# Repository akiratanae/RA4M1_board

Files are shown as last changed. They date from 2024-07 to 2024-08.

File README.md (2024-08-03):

# 多機能マイコンボード
## 概要
- 手ごろな価格で入手でき、高性能で多機能なルネサス社マイコンRA4M1(R7FA4M1AB3CFM)
- USBホストまたはUSBファンクション機能をオンボードで使用可能
- RS485をオンボードで使用可能
- CANをオンボードで使用可能
- マイコン内蔵の豊富なアナログ機能をオンボードで使用可能
- 多数のマイコン端子にコネクタを通して外部からアクセス可能

# 使用法
## motorolaヘキサファイルの書込み
接続図
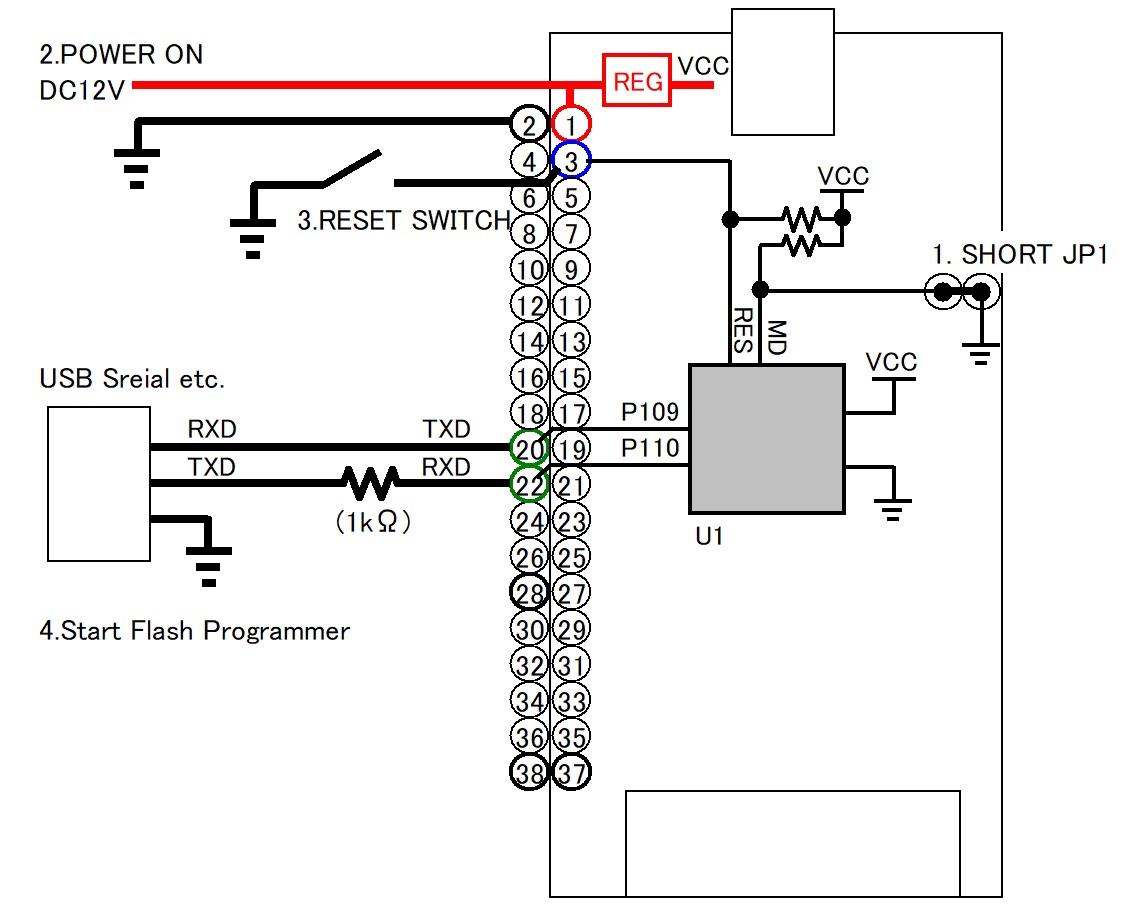
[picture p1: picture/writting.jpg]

手順  
1. JP1をショート(MD端子=LOW)
2. 電源ON
3. RES端子をLOWからHIに(図では外部リセットボタン)
4. Renesas Flash Programmerをスタート

## 使用例
外部からDC12V供給、USBホスト
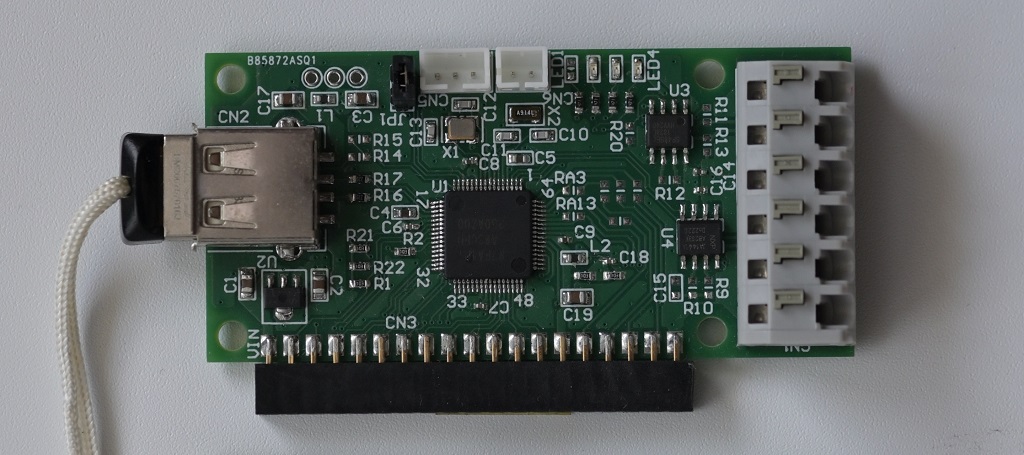
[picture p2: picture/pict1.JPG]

USBバスパワー
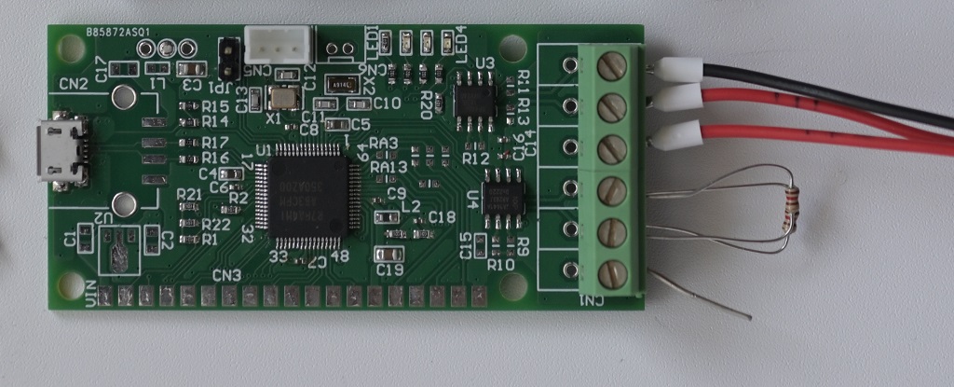
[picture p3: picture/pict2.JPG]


## versatile functional control board using renesas RA4M1 microcontroller.
- High performance and versatile but low cost microcontroller(R7FA4M1AB3CFM)
- on board USB Host or Function
- on board RS485
- on board CAN
- on chip analog functions are accessed by on board configuration
- Many pins accessible for use from outside.

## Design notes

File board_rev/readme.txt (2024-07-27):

CNTRL_SA.GTL  L1 pattern
CNTRL_SA.GBL  L2 pattern
CNTRL_SA.GTS  L1 solder resist
CNTRL_SA.GBS  L2 solder resist
CNTRL_SA.GTO  L1 silk
CNTRL_SA.GM1  mechanical outline
CNTRL_SA.TXT  drill

layer 2
size 35x74mm

revision : delete one led and add one user jumper.

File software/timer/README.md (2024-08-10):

# Simple Interrupt Software
## 概要
RA4M1のタイマ(AGT)を使用したLED点滅ソフトウェア
## e2studioでの手順
1. 新規Renesas C/C++ projectでプロジェクト作成(device=R7FA4M1AB3CFM)
2. ConfigurationのClockでクロック確認(XTAL=12MHz, ICLK=48MHzなど)
3. ConfigurationのPinでLED端子(P303,P304,P113)を出力に設定
4. ConfigurationのInterruptsでAGT0 INTイベントにISRを追加
5. Generate Project Contentボタンでコード生成
6. ra_gen/main.cをビルド対象から外す
7. srcにmain.cを追加、編集。タイマ割込みハンドラ名は4で指定したISR名
8. プロジェクトのビルド
## 備考
- IRQ(16番目から)のベクタテーブルは、ConfigurationでISR登録するとra_gen\vector_data.cに順番に作成される
- RA4M1には僅か32しか登録できる割込みベクタが無いので注意

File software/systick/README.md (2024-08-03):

# First Software
## 概要
CortexM4のSysTickタイマを使用したLED点滅ソフトウェア
## e2studioでの手順
1. 新規Renesas C/C++ projectでプロジェクト作成(device=R7FA4M1AB3CFM)
2. ConfigurationのClockでクロック確認(XTAL=12MHz, ICLK=48MHzなど)
3. ConfigurationのPinでLED端子(P303,P304,P113)を出力に設定
4. Generate Project Contentボタンでコード生成
5. ra_gen/main.cをビルド対象から外す
6. srcにmain.cを追加、編集
7. プロジェクトのビルド
## 備考
- 0番地からSysTick(15番目)までのベクタテーブルは、startup.cで設置されている

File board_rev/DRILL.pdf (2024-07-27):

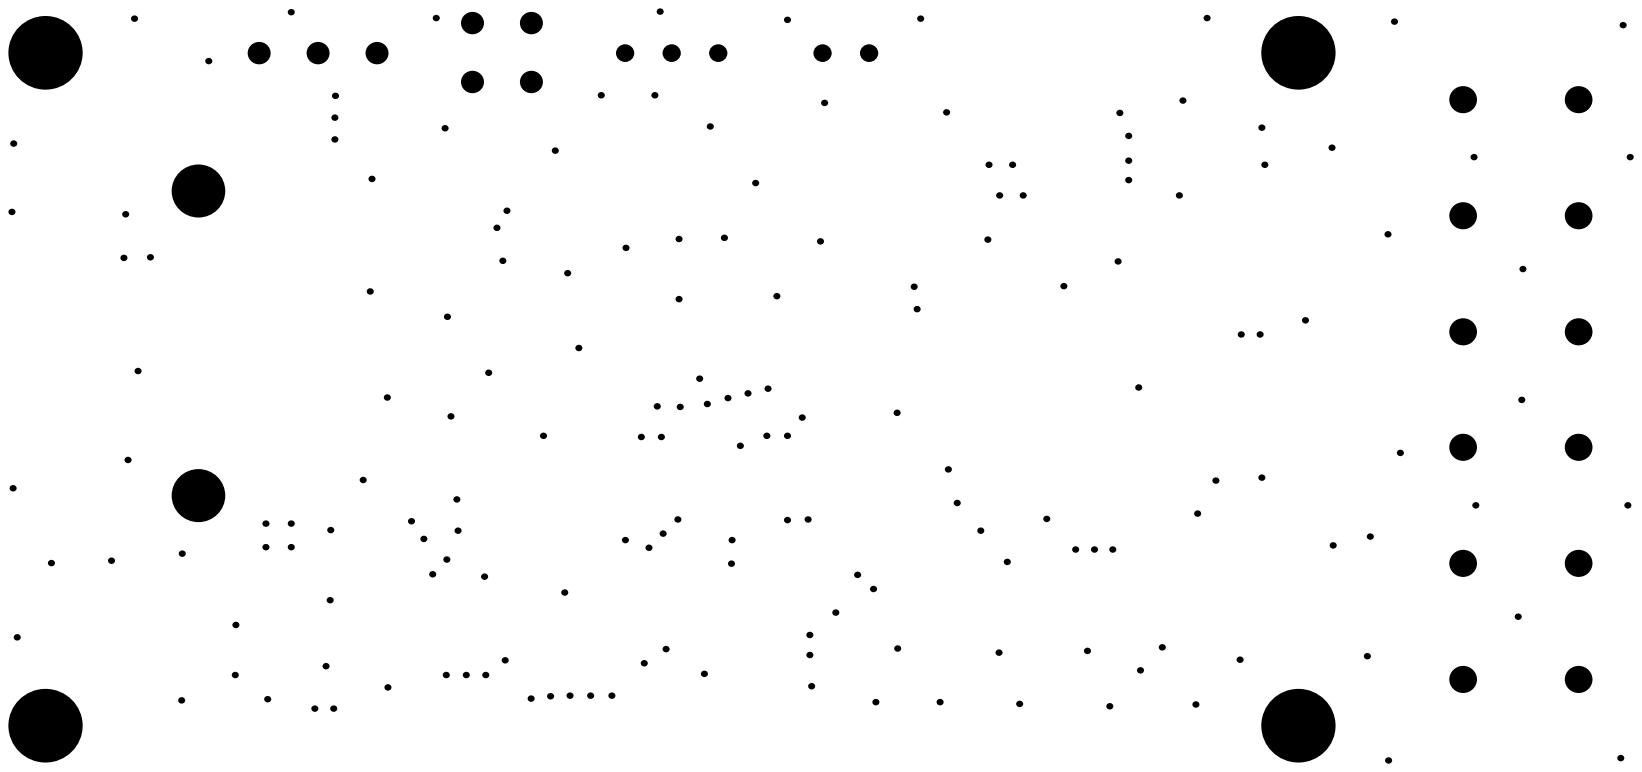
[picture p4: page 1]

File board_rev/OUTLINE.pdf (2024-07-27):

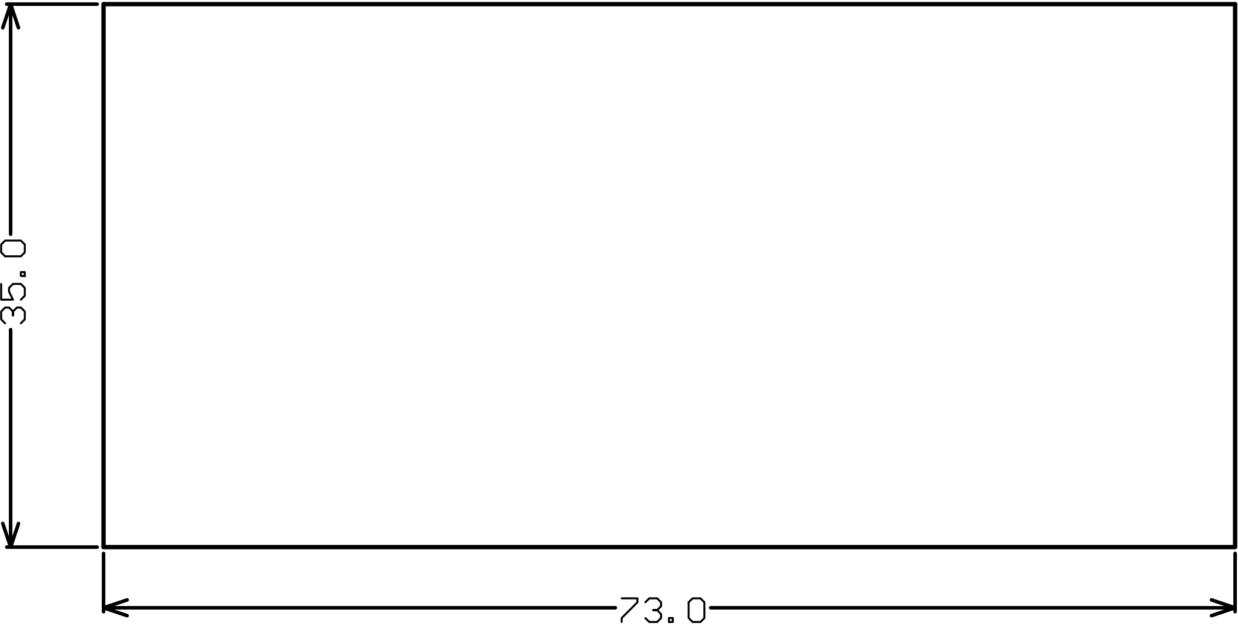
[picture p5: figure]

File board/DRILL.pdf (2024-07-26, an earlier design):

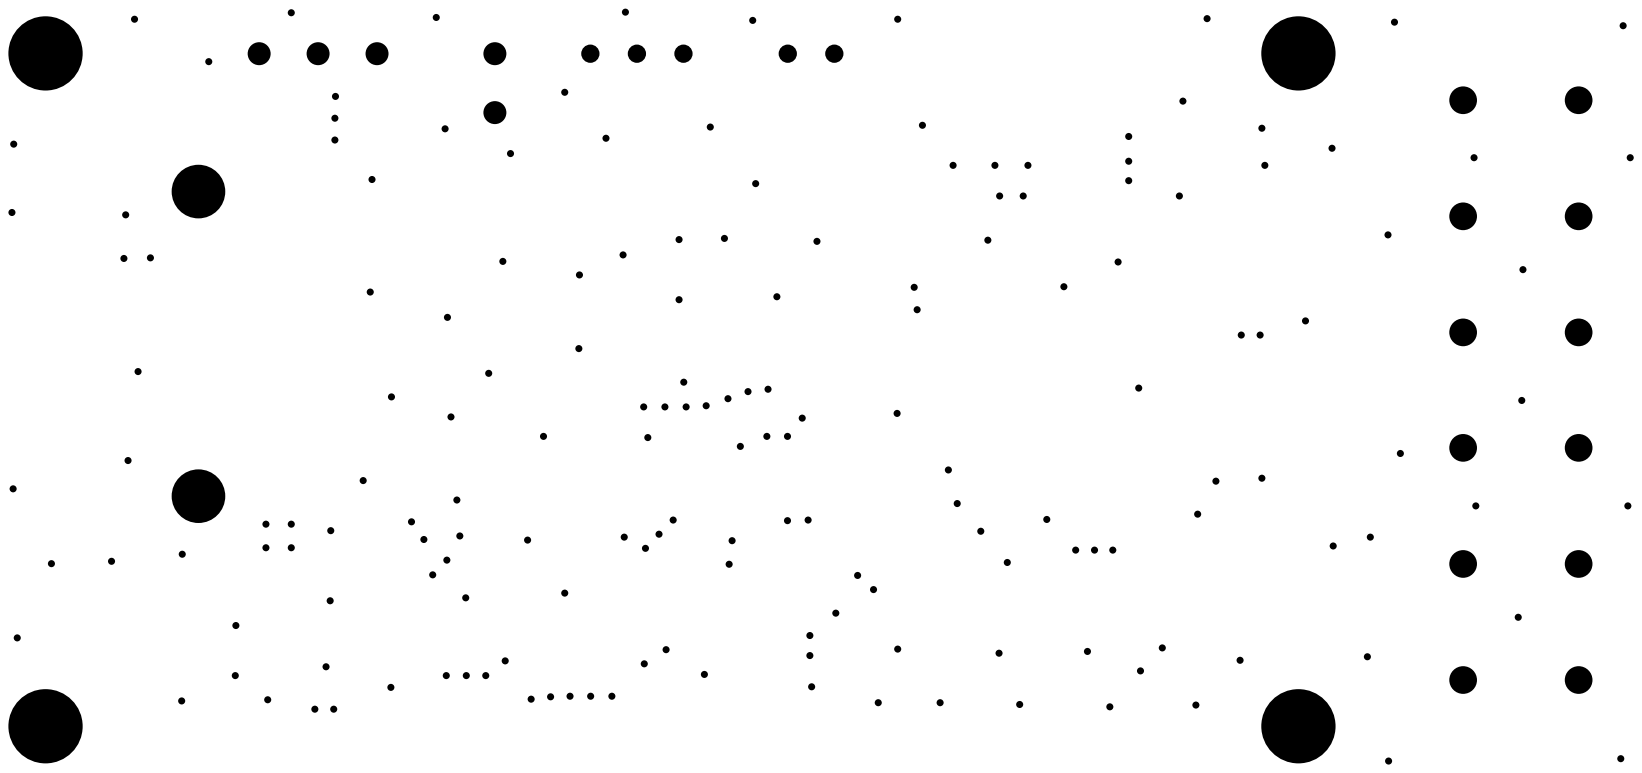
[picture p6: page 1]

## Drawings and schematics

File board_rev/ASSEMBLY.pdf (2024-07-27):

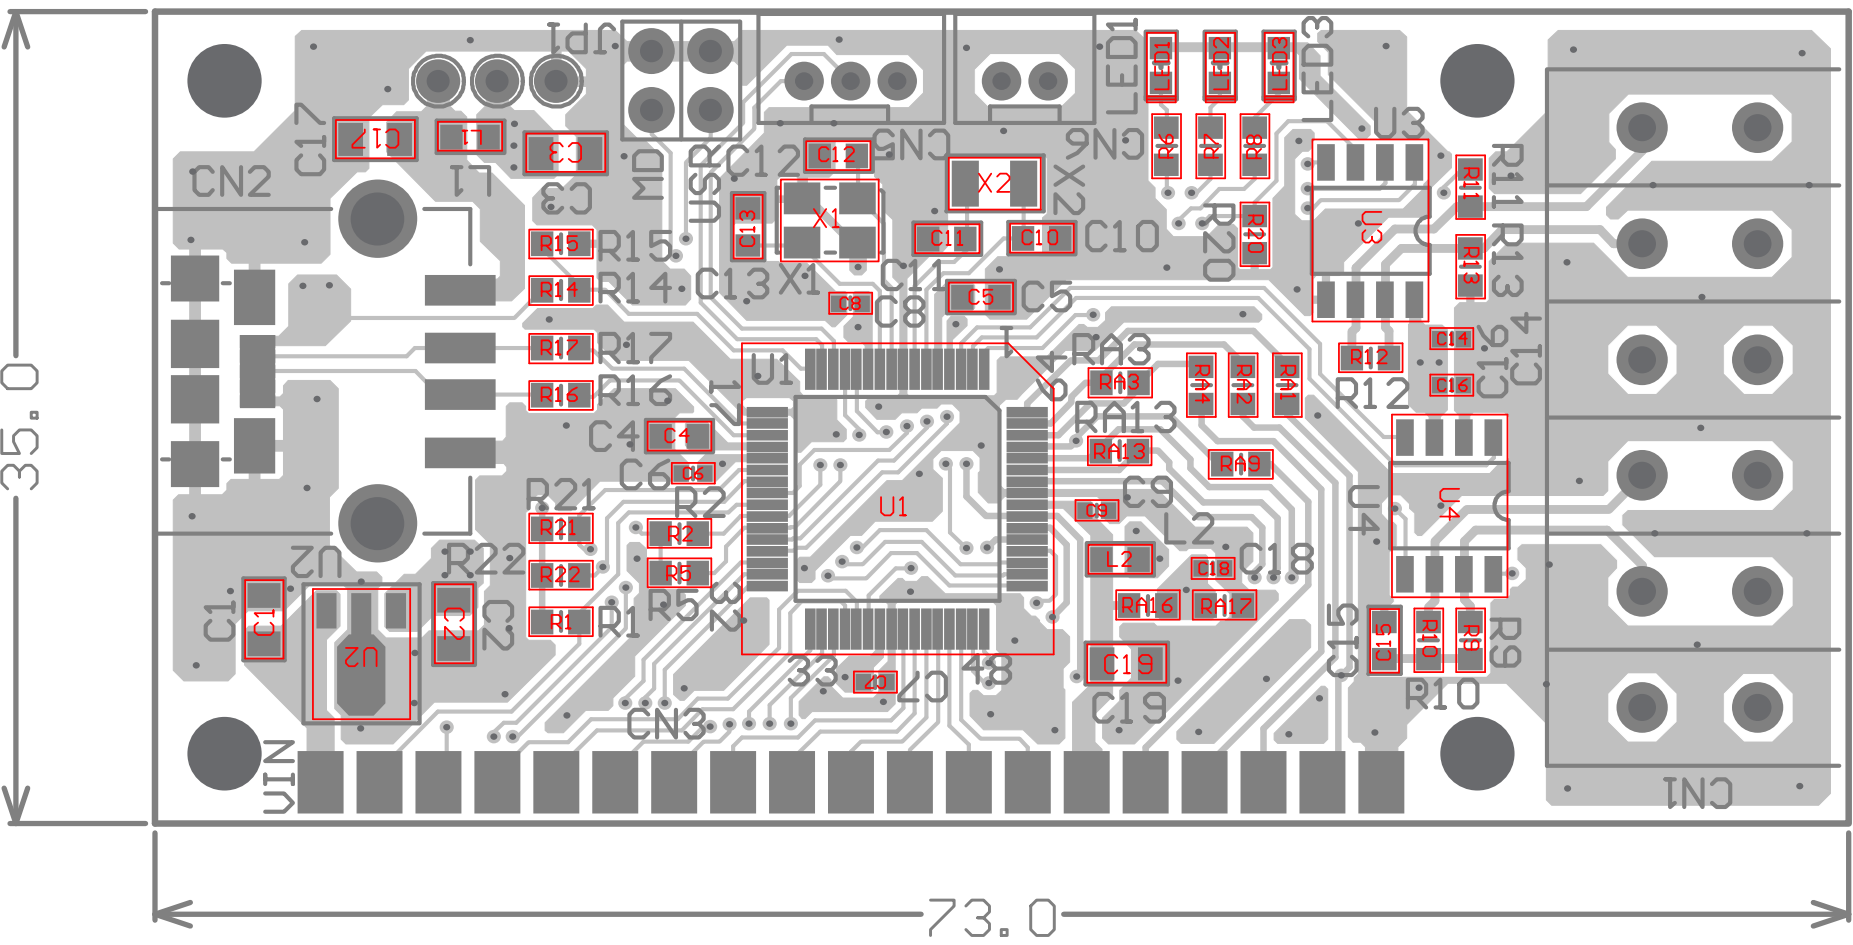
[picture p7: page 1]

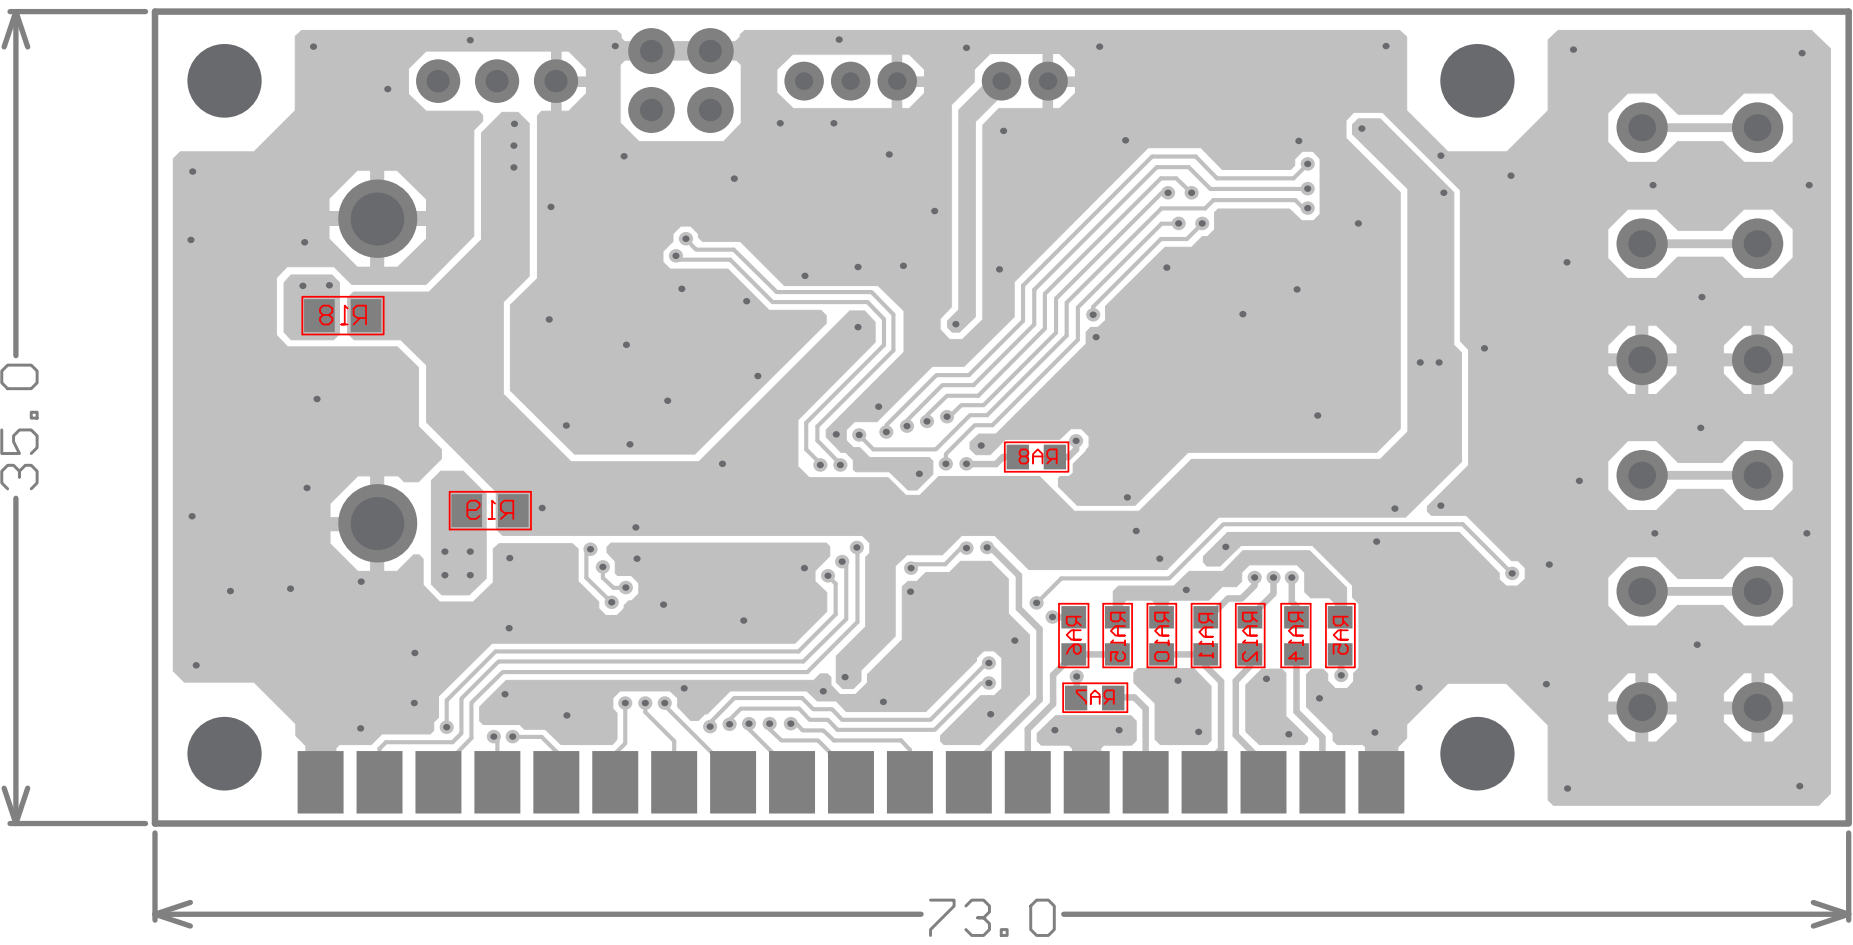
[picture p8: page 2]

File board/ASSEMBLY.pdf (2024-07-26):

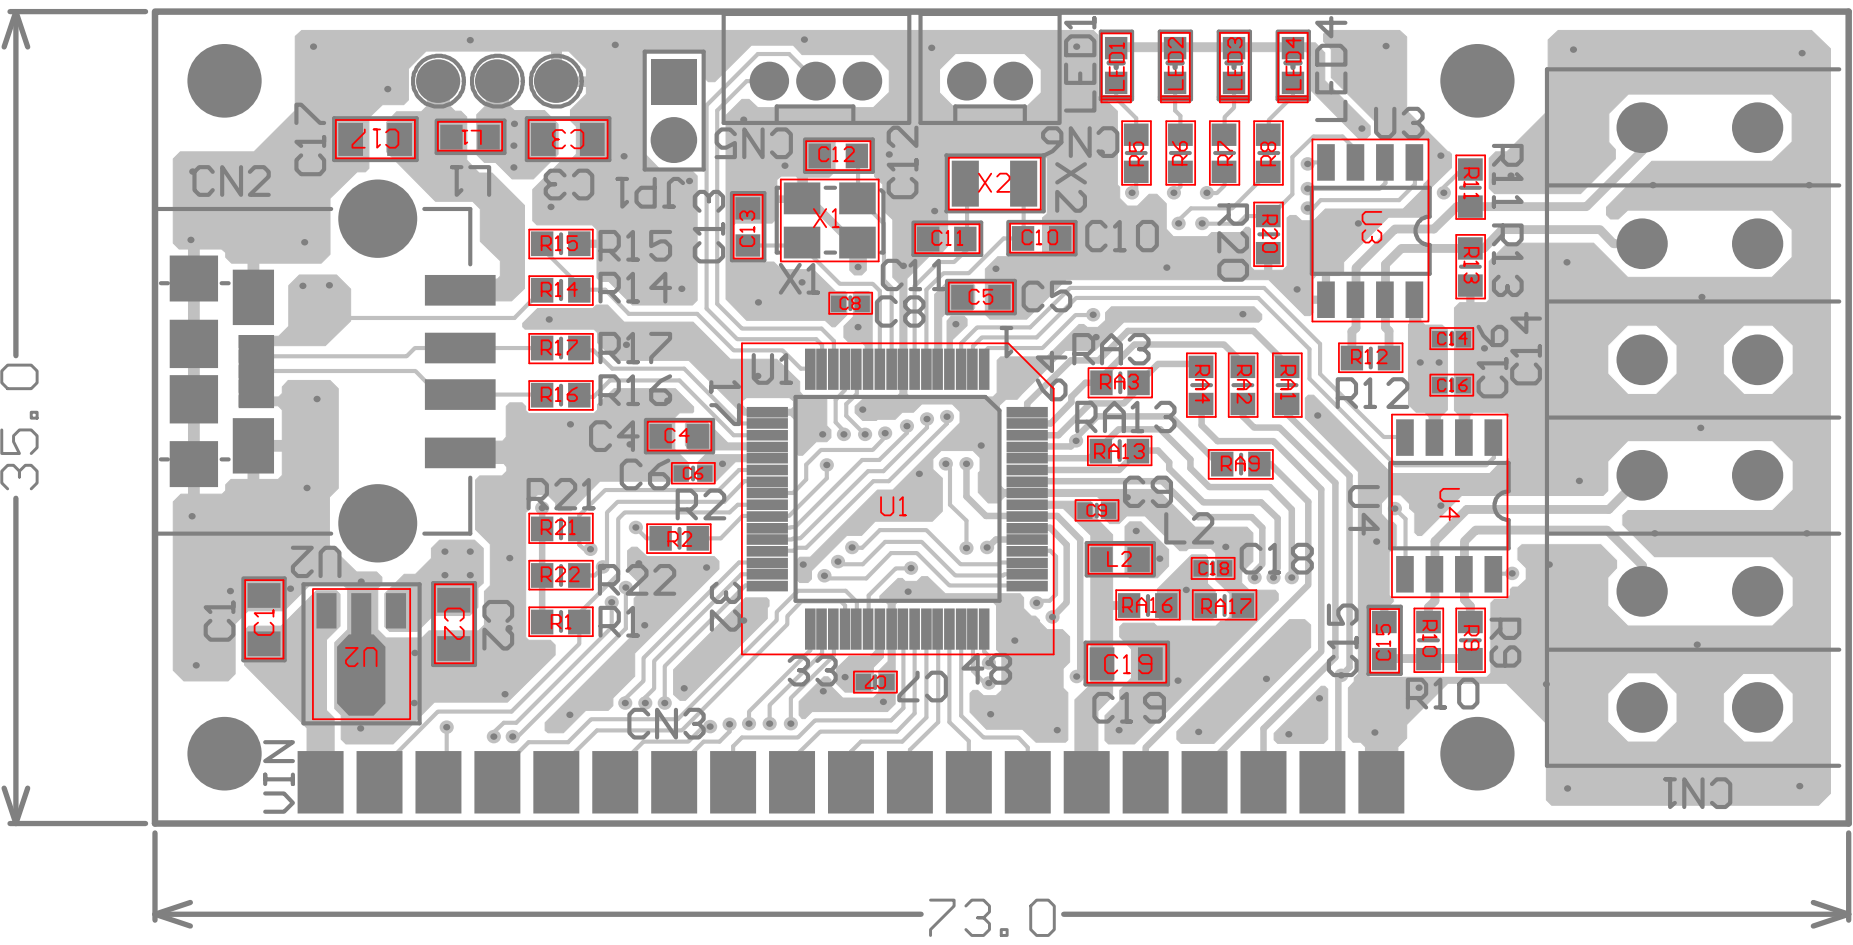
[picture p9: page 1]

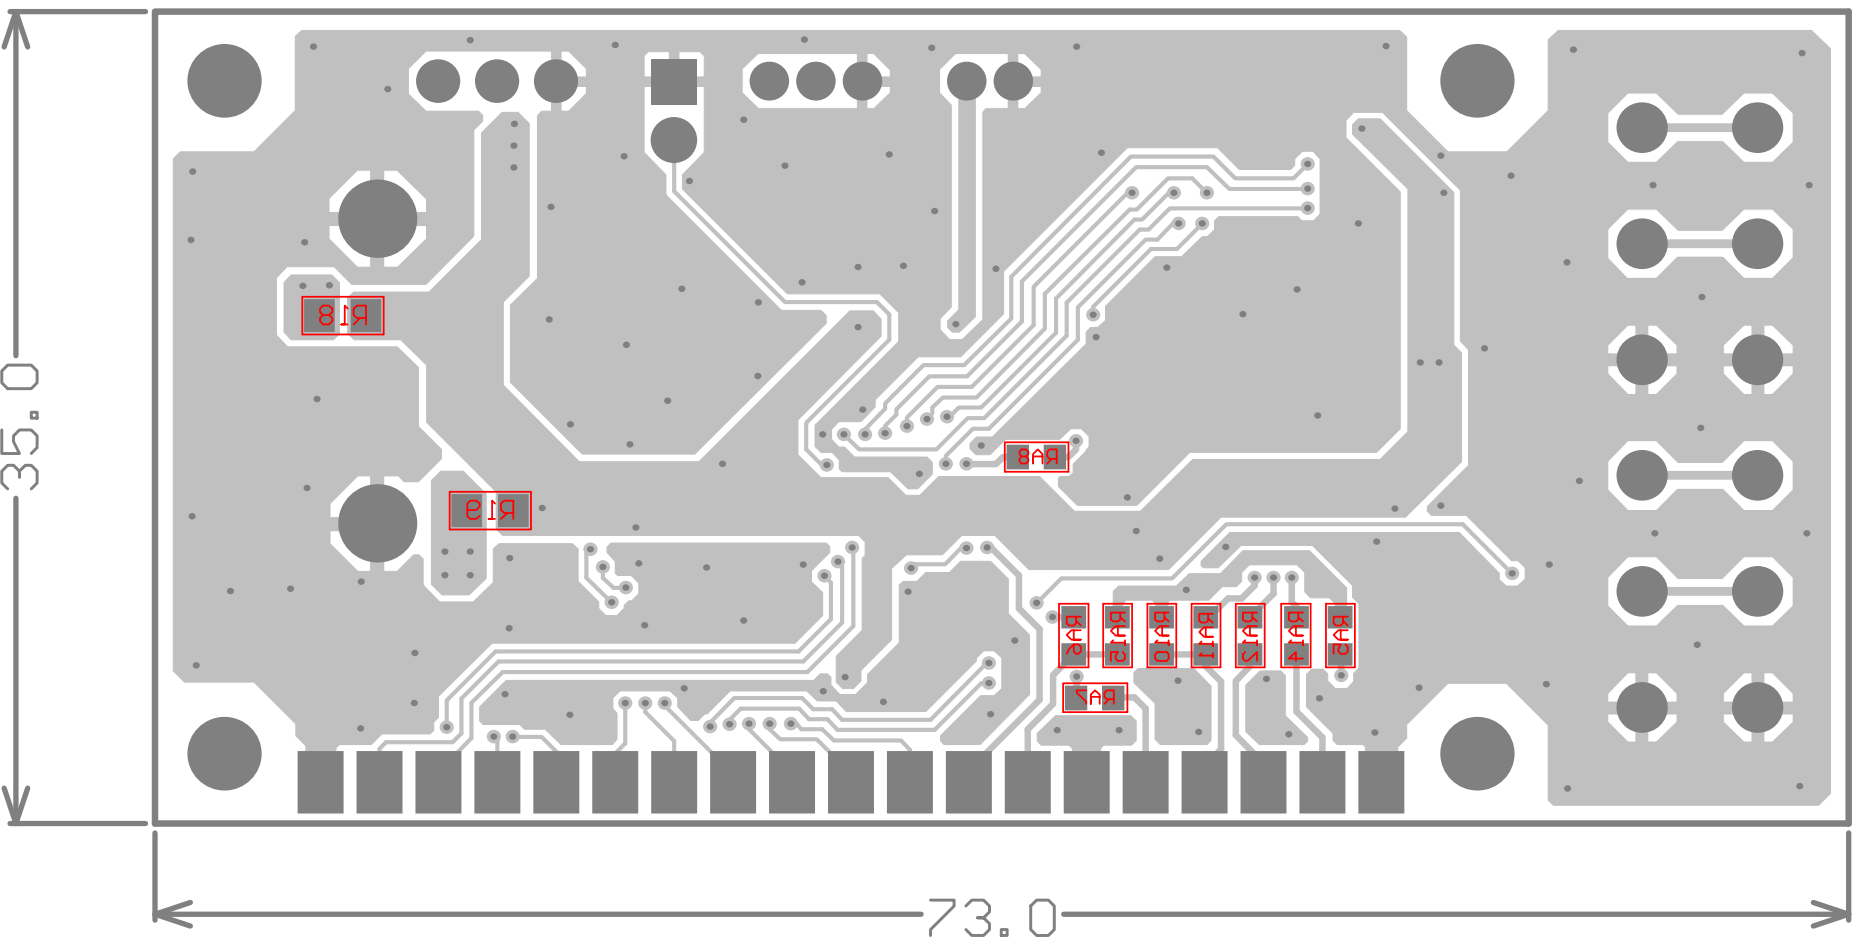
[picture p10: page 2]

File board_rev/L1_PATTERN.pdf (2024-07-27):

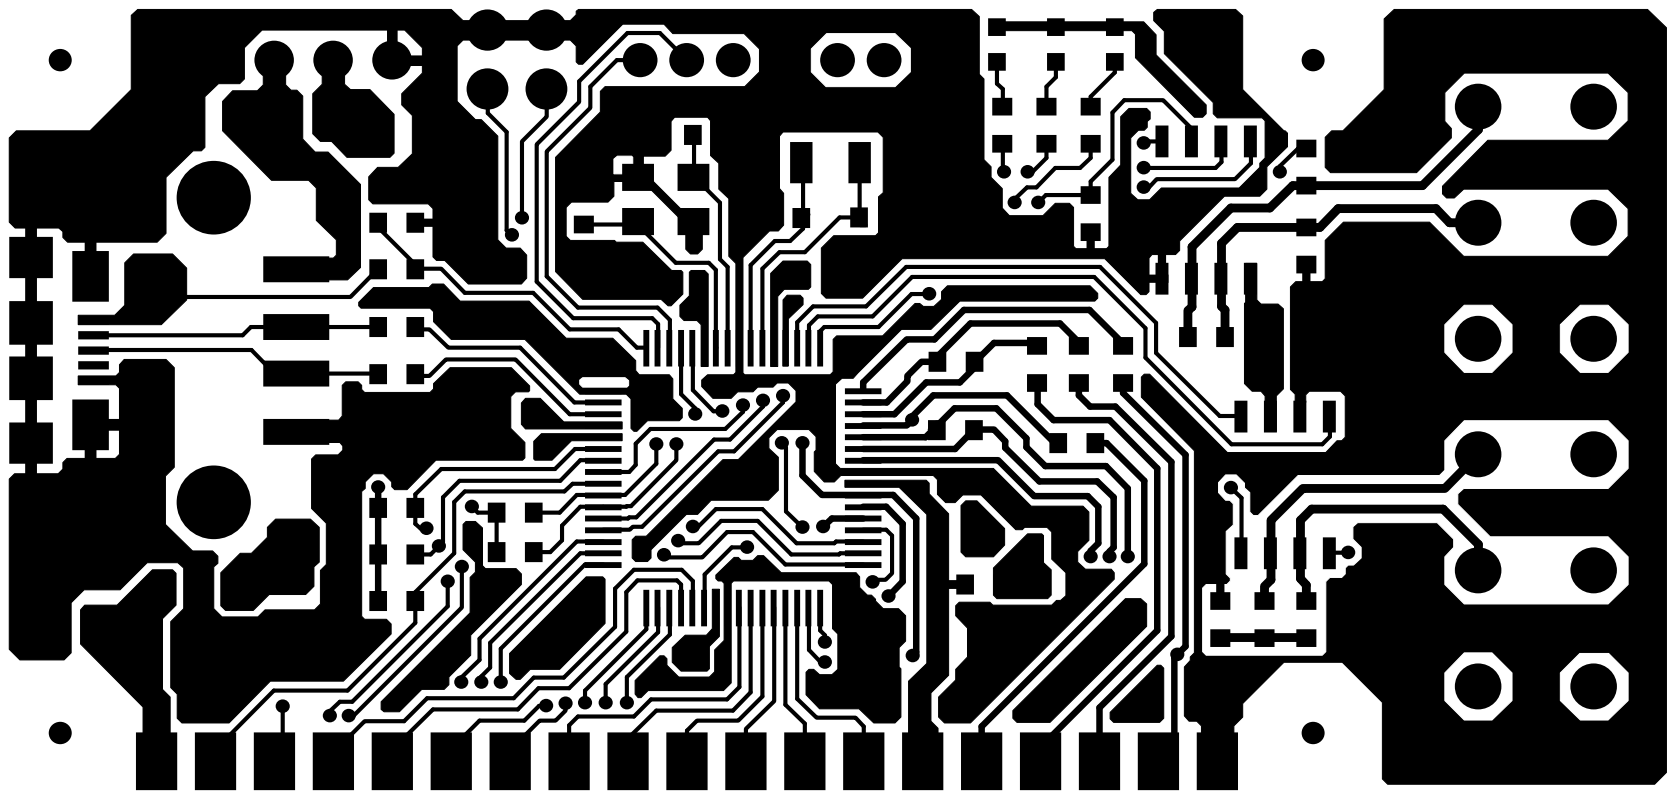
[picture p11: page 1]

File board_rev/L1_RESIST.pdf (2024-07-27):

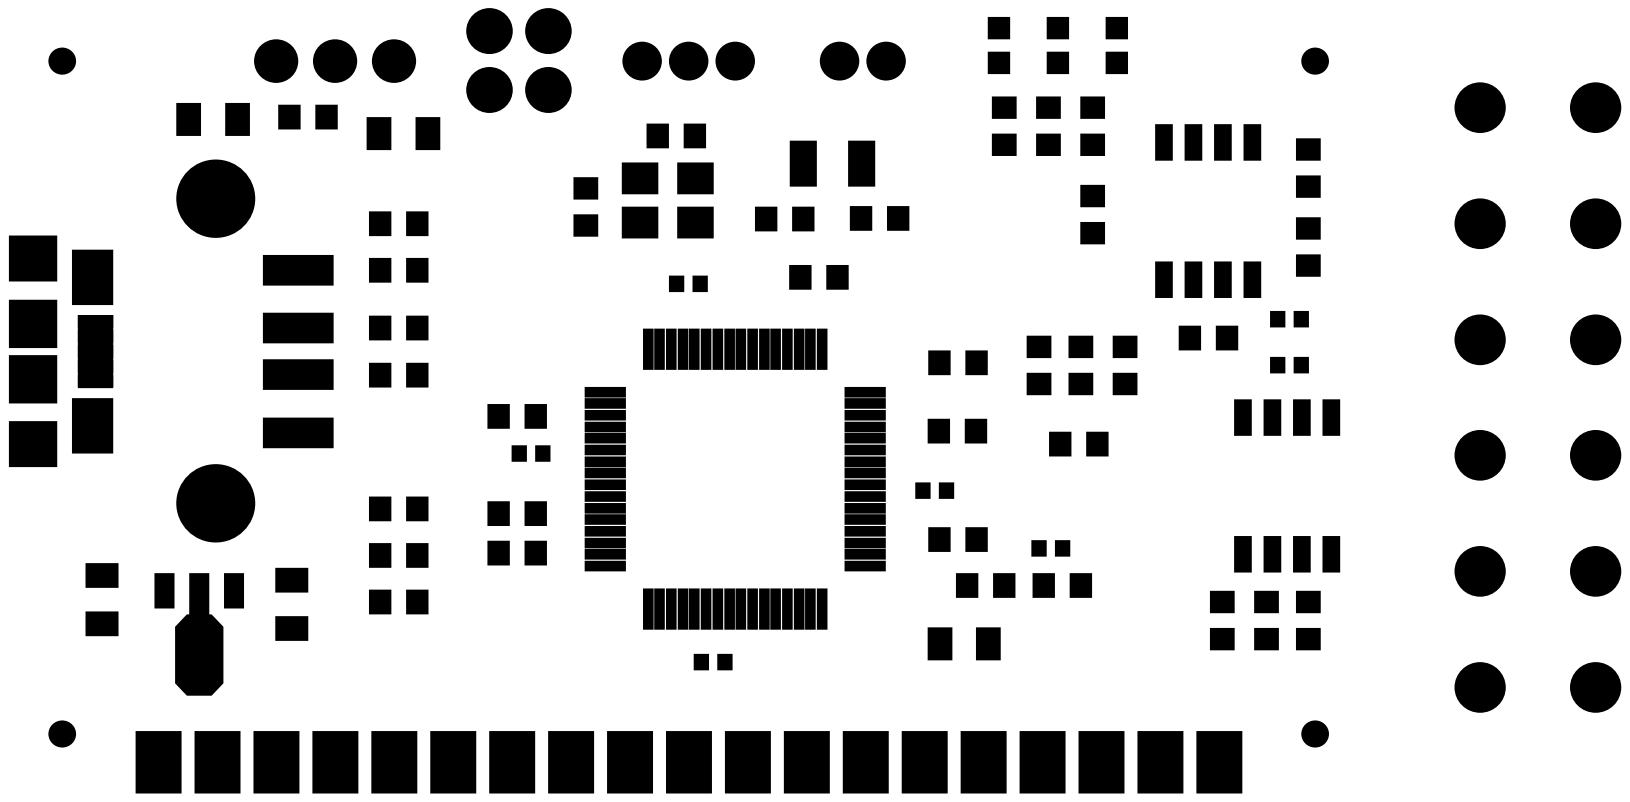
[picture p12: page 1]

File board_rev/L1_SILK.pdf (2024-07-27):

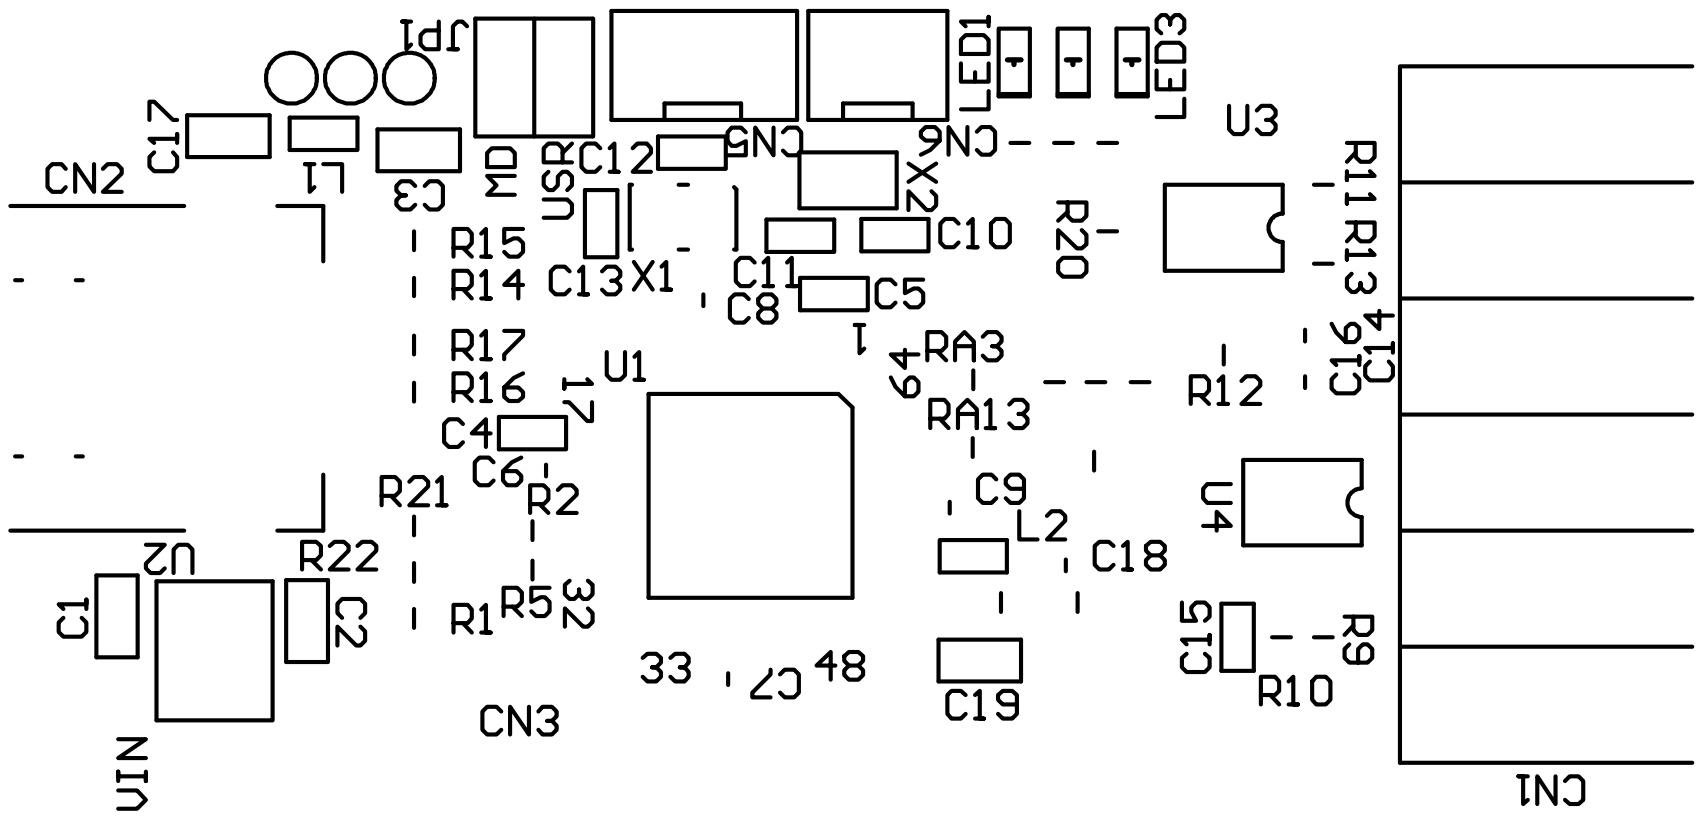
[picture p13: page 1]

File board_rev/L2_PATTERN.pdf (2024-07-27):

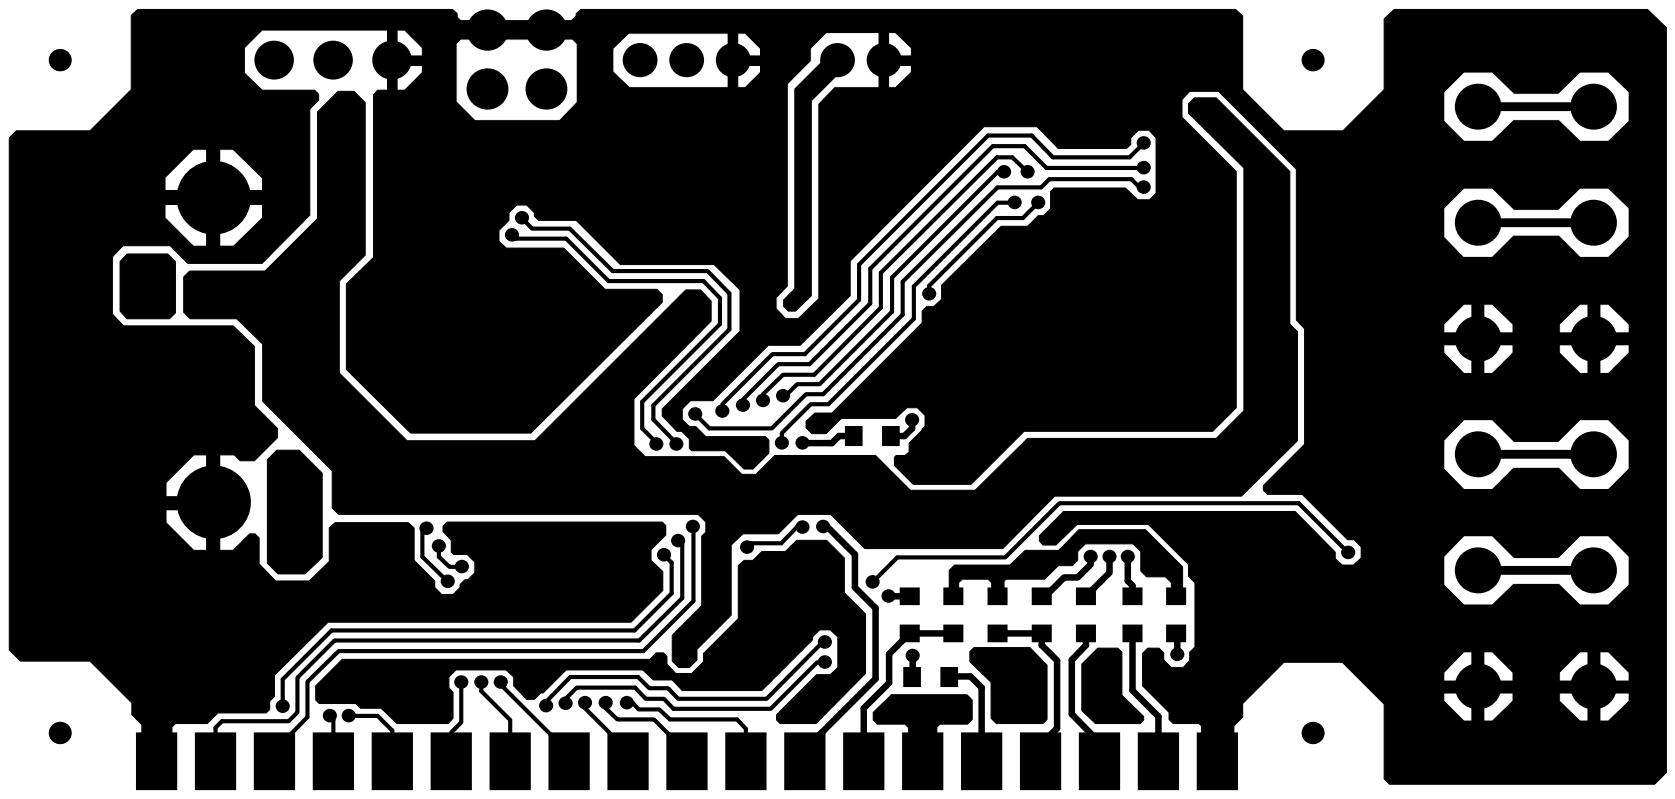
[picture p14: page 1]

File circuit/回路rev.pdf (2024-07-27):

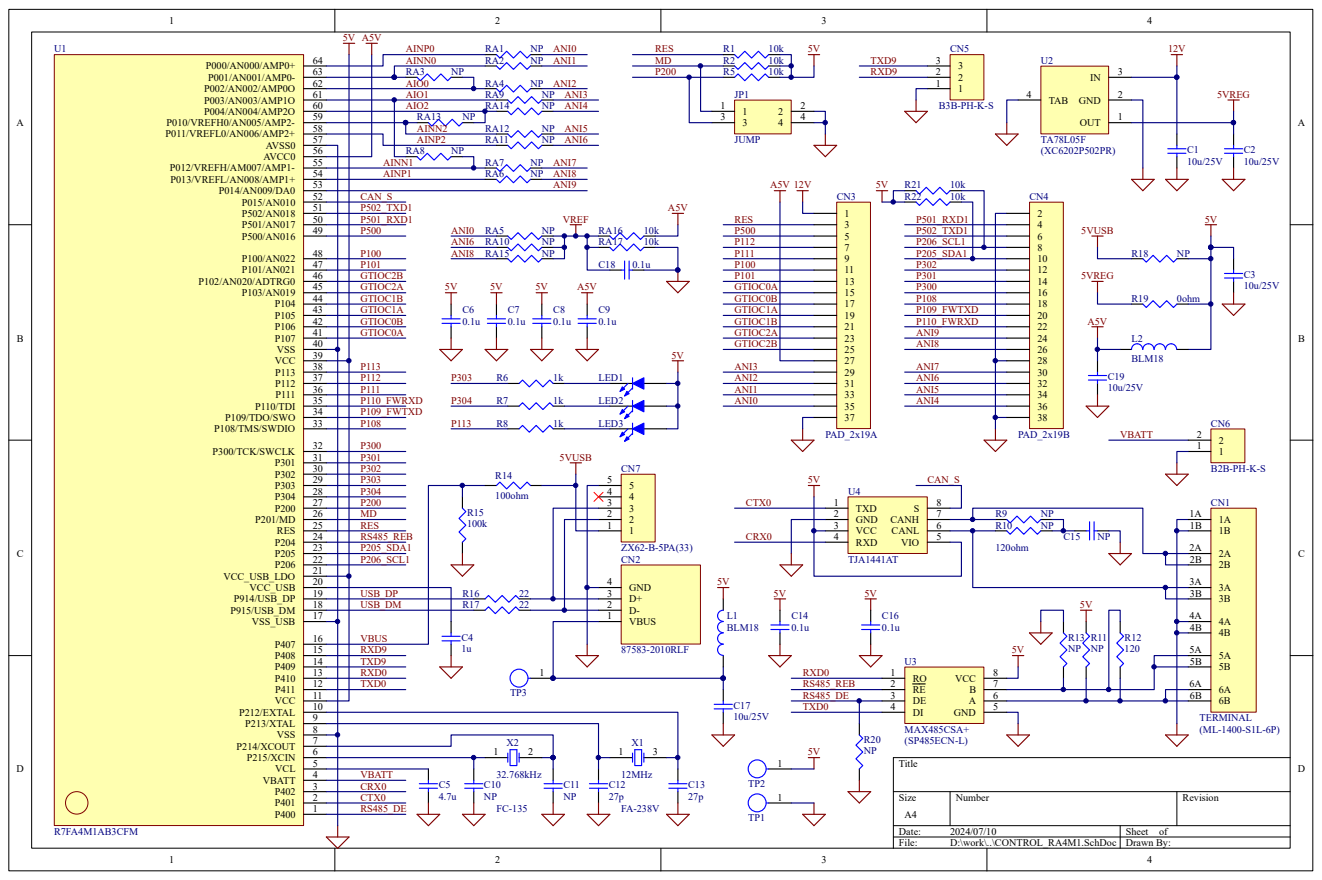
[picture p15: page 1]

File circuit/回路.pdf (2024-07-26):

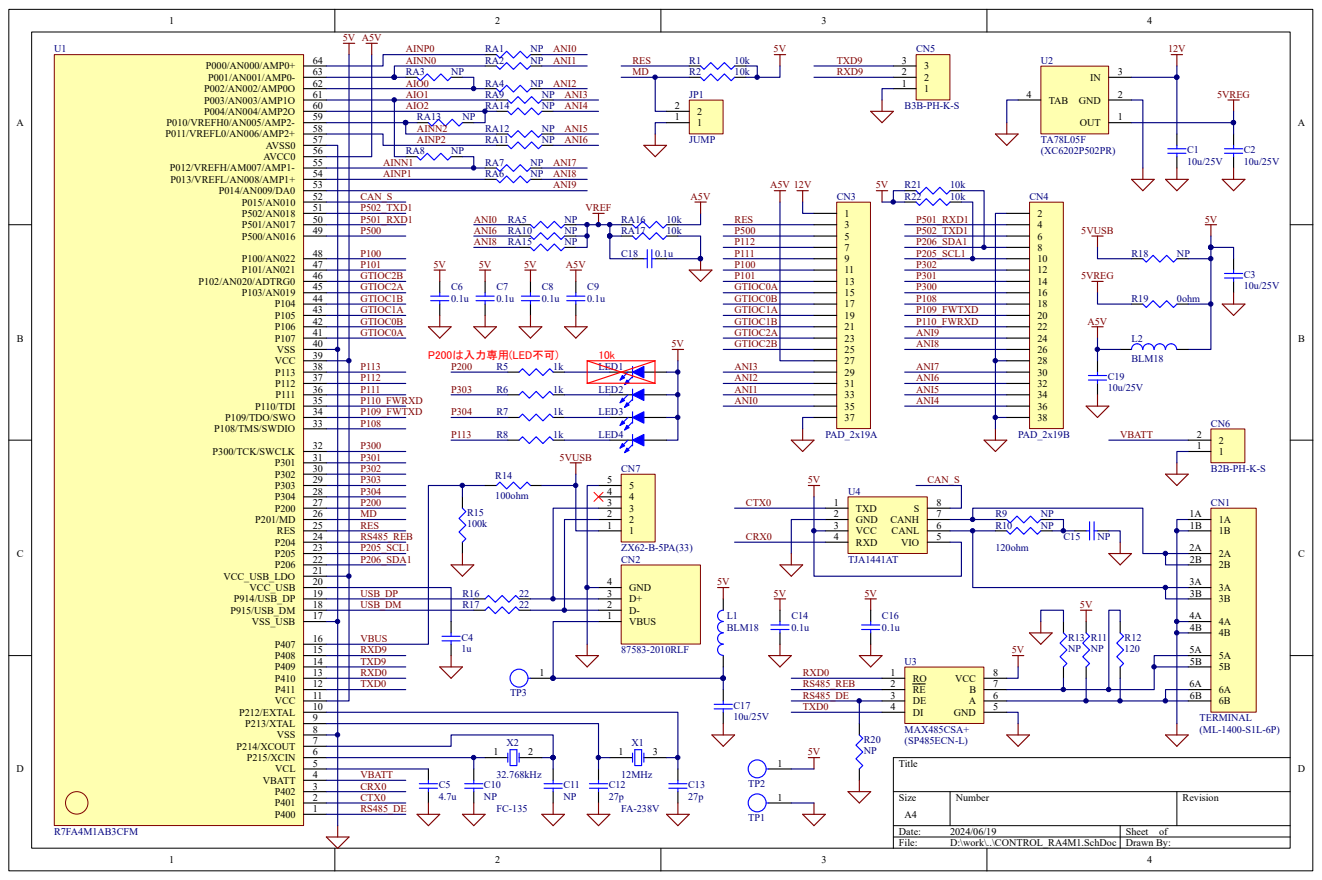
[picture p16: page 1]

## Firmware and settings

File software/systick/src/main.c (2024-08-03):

#include "hal_data.h"

#include "control_board.h"

volatile uint8_t count_10ms;
volatile uint8_t count_sec;
volatile uint8_t timer_flag;

void SysTick_Handler(void)
{
	count_10ms++;
	if (count_10ms >= 10) {
		count_10ms = 0;
		timer_flag = 1;
		/*LED3 = ~LED3;*/
	}

}

void process_10ms(void)
{
	count_sec++;
	if (count_sec >= 100) {
		count_sec = 0;
		LED1 = ~LED1;
	}
}

int main(void)
{
	timer_flag = 0;
	count_10ms = 0;
	count_sec = 0;

	SysTick_Config(48000);	/* SystemCoreClock 48MHz/1000*/
	
	for (;;) {
		if (timer_flag) {
			timer_flag = 0;
			process_10ms();
			/*LED2 = ~LED2;*/
		}
	}

	return 0;
}

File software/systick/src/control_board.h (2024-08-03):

#ifndef _CONTROL_BORARD_H_
#define _CONTROL_BORARD_H_

#define FW_VERSION		0x10

#define LED1	R_PORT3->PODR_b.PODR3
#define LED2	R_PORT3->PODR_b.PODR4
#define LED3	R_PORT1->PODR_b.PODR13

#define CAN_SILENT	R_PORT0->PODR_b.PODR15

#define RS485_REB	R_PORT2->PODR_b.PODR4
#define RS485_DE	R_PORT4->PODR_b.PODR0

#define INT_PRIORITY_SCI0_TX		(0x08)
#define INT_PRIORITY_SCI0_RX		(0x08)


#endif /*_CONTROL_BORARD_H_*/

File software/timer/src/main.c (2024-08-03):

#include "hal_data.h"

#include "control_board.h"

volatile uint8_t count_10ms;
volatile uint8_t count_sec;
volatile uint8_t timer_flag;

#define INT_PRIORITY_AGT0_INT	8

void agt0_int_isr(void)
{
    R_BSP_IrqStatusClear(AGT0_INT_IRQn);

	count_10ms++;
	if (count_10ms >= 10) {
		count_10ms = 0;
		timer_flag = 1;
		/*LED3 = ~LED3;*/
	}
}

void agt0_init(void)
{
	R_BSP_MODULE_START(FSP_IP_AGT, 0);
	R_BSP_IrqDisable(VECTOR_NUMBER_AGT0_INT);
	R_BSP_IrqStatusClear(VECTOR_NUMBER_AGT0_INT);
	R_BSP_IrqCfg(VECTOR_NUMBER_AGT0_INT, INT_PRIORITY_AGT0_INT, (void *)0);
	R_AGT0->AGT16.AGT = 0x5dbf;
	R_AGT0->AGT16.CTRL.AGTMR1 = 0x00;
	R_BSP_IrqEnable(VECTOR_NUMBER_AGT0_INT);
}

void process_10ms(void)
{
	count_sec++;
	if (count_sec >= 100) {
		count_sec = 0;
		LED1 = ~LED1;
	}
}

int main(void)
{
	agt0_init();

	timer_flag = 0;
	count_10ms = 0;
	count_sec = 0;

	/* start timer */
	R_AGT0->AGT16.CTRL.AGTCR_b.TSTART = 1;

	for (;;) {
		if (timer_flag) {
			timer_flag = 0;
			process_10ms();
			/*LED2 = ~LED2;*/
		}
	}

	return 0;
}

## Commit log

2024-07-26 誤記修正
2024-07-27 add reviced circuit data
    [CNTRL_SA.GBL, CNTRL_SA.GBS, CNTRL_SA.GM1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]
2024-08-03 add software samples
2024-08-10 READMEの修正
